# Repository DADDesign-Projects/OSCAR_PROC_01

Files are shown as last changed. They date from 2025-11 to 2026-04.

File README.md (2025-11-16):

# OSCAR Processor Board - OSCAR_PROC_01






# 📋 Description
Dedicated electronic board implementing the processor section of the OSCAR effects pedal (https://github.com/DADDesign-Projects/OSCAR_P01A01). This board handles digital signal processing and audio control for the OSCAR effects platform.

# 🛠️ Technical Specifications
## Microcontroller STM32H743:
 - High-performance ARM Cortex-M7 MCU
 -  480 MHz frequency
 -  2MB Flash memory
 -  1MB RAM
## Flash Memory 2* W25Q128
 - 32 Moctet.
 - Double mode 8 bits SPI;
 - 120 Mhz
## SDRAM Memory IS42S16320
 - 64 Moctet
 - 200 Mhz
## USB OTG FS
  - CDC Virtual port COM
  - UDP DownLoad Firmware Update
  - MIDI / USB
## I/O
  - 4 Encoders
  - 2 Switchs
## TFT
  - SPI inteface 
  - 2.4 inch 
## MIDI
  - UART TRS Midi in
## Orogramming/Debugging
  - STLink serial port
  - USB UDP protocol.

## 💻 Software
The circuit design software for this board is available in the OSCAR repository (https://github.com/DADDesign-Projects/OSCAR_P01A01). This project is built upon the DAD Forge framework (https://github.com/DADDesign-Projects/DAD_FORGE), which provides a standardized foundation for hardware development and collaboration.

## 🛠️ Design Tools
This project was entirely designed using KiCad 9.0, the open-source electronics design automation suite.
    
# 📬 Contact
Feel free to contact me for any questions, feedback, improvement suggestions, or collaboration proposals related to the FORGE framework or the OSCAR hardware platform.
I am always open to discussion and community contributions (daddesign.projects@gmail.com).  
  
---

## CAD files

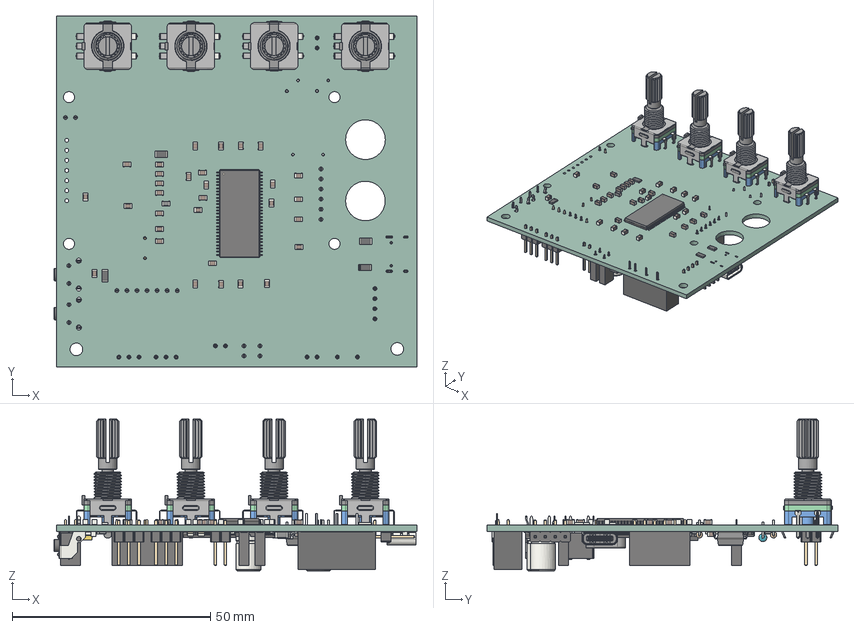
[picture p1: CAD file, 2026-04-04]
OSCAR_Proc.step
91.6 x 88.6 x 38.3 mm
C_0805_2012Metric x 36
EC11_Rotary_Encoder_Switched x 4
R_1206_3216Metric x 10
TSOP-II-54_22.2x10.16mm_P0.8mm
L_0805_2012Metric
LED_1206_3216Metric x 2
CP_Elec_6.3x9.9 x 2
SOIC-8_5.3x5.3mm_P1.27mm x 2
CP_EIA-3528-21_Kemet-B
PinSocket_1x07_P2.54mm_Vertical
PinSocket_1x02_P2.54mm_Vertical x 3
L_1206_3216Metric x 2
PinHeader_1x04_P2.54mm_Horizontal
SOT-23
USB_C_Receptacle_GCT_USB4105-xx-A_16P_TopMnt_Horizontal
SW_Tactile_SPST_Angled_PTS645Vx39-2LFS x 2
PinHeader_1x02_P2.54mm_Vertical x 2
Crystal_HC49-4H_Vertical
PinHeader_1x03_P2.54mm_Vertical x 2
B0512S-2W
D_DO-35_SOD27_P7.62mm_Horizontal
SOT-143
LQFP-176_24x24mm_P0.5mm
PinSocket_1x06_P2.54mm_Vertical
R_Axial_DIN0204_L3.6mm_D1.6mm_P7.62mm_Horizontal x 2
SOT-223
User Library-DIP-6-SMD
OSCAR_Proc_PCB

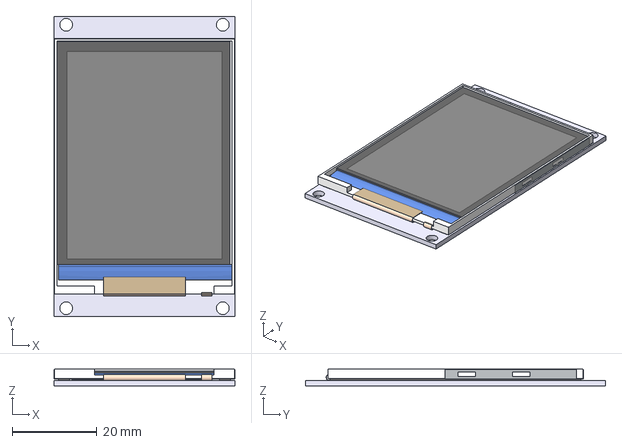
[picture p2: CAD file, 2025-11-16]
TFT_2_4_CStd.step
42.8 x 71.0 x 4.02 mm
2.4in TFT(Without Glass)- Tucked Cable
Corps

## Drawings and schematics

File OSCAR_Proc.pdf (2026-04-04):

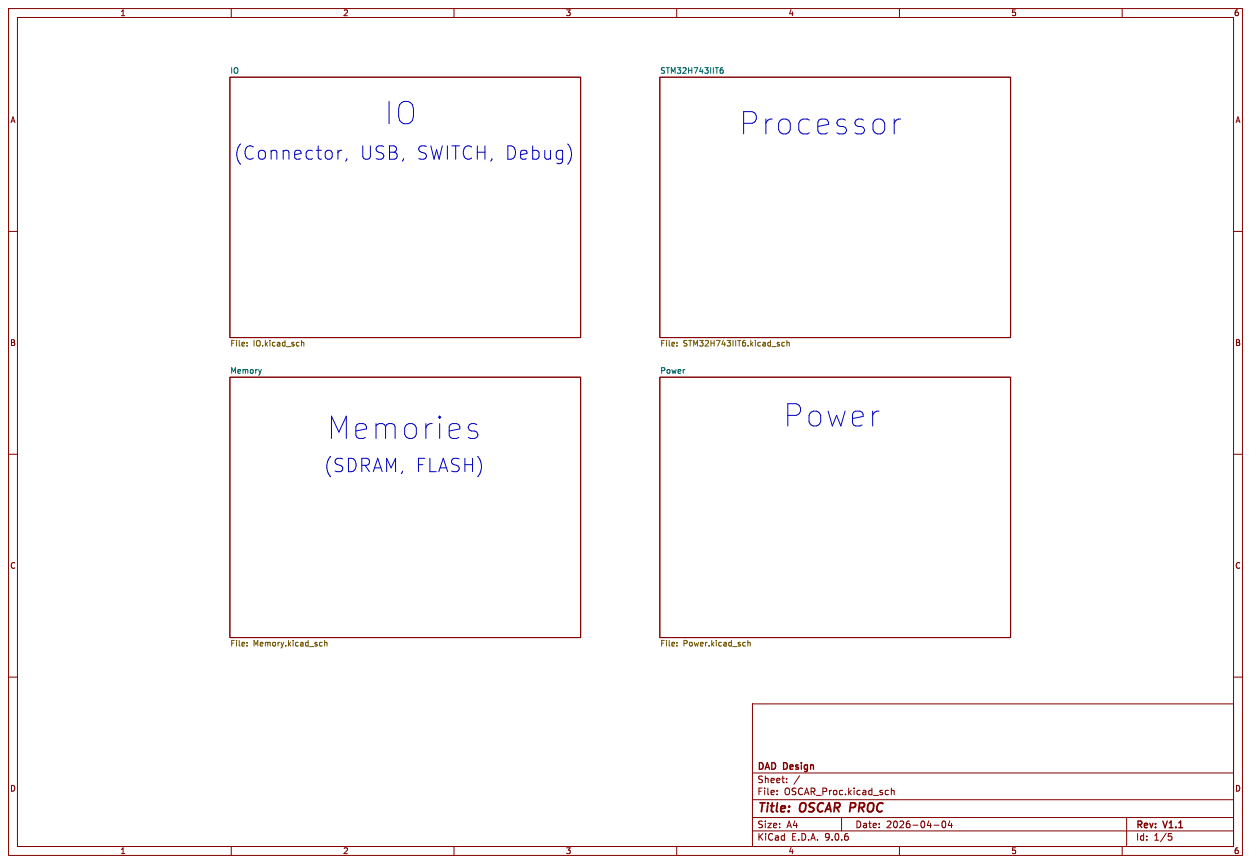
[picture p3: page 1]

File: IO.kicad_sch Memory File: Memory.kicad_sch

Id: 1/5 Title: OSCAR PROC

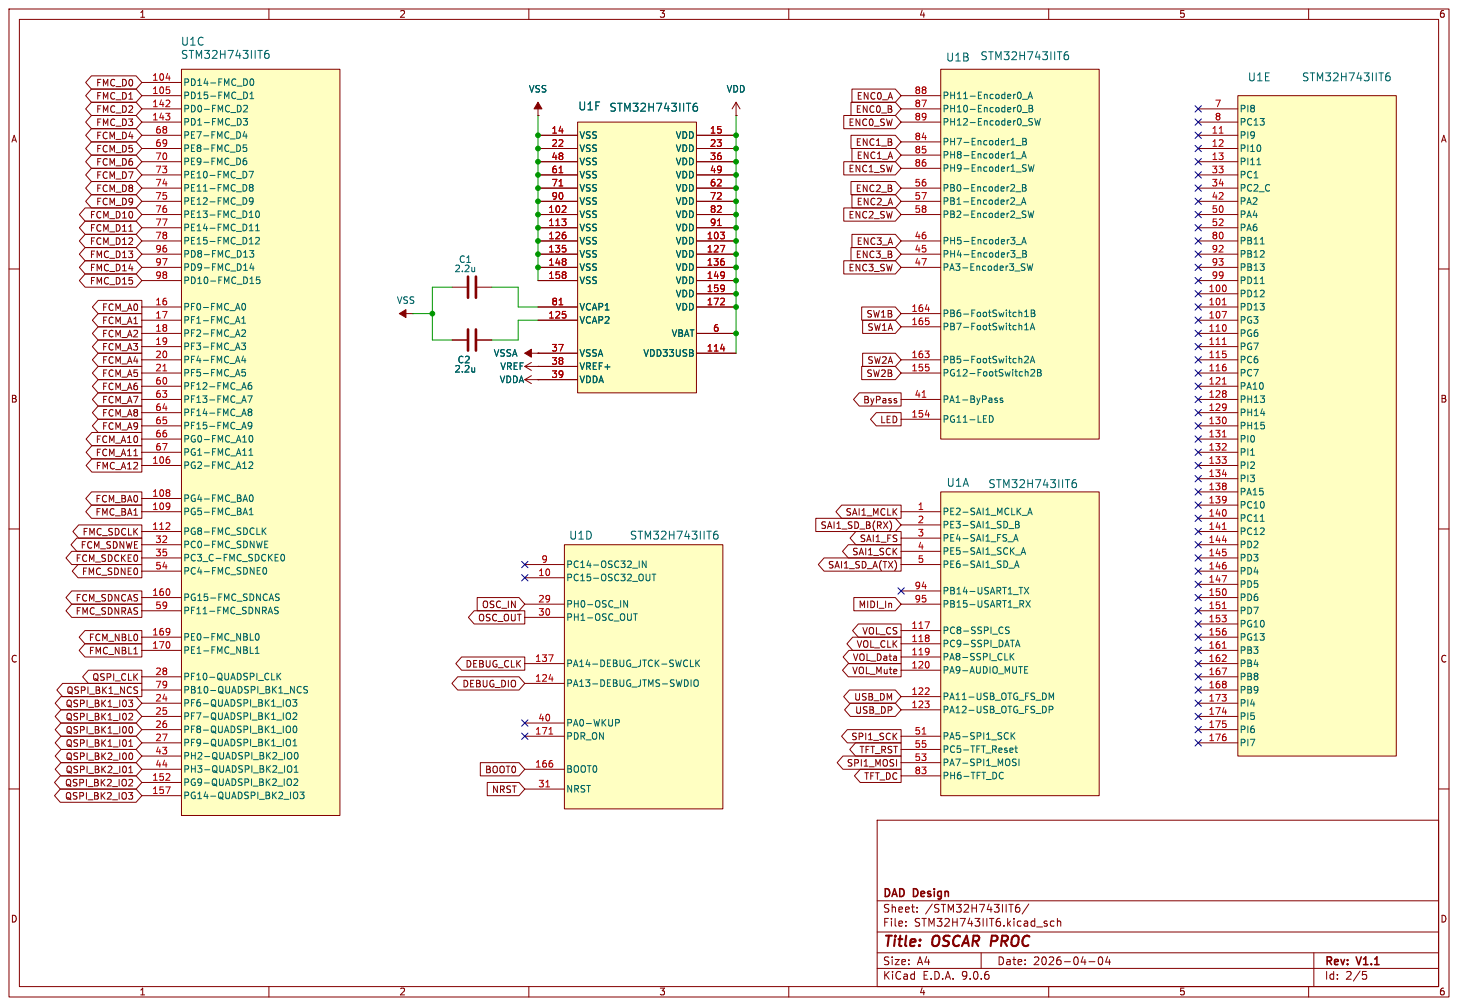
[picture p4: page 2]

Id: 2/5 Title: OSCAR PROC

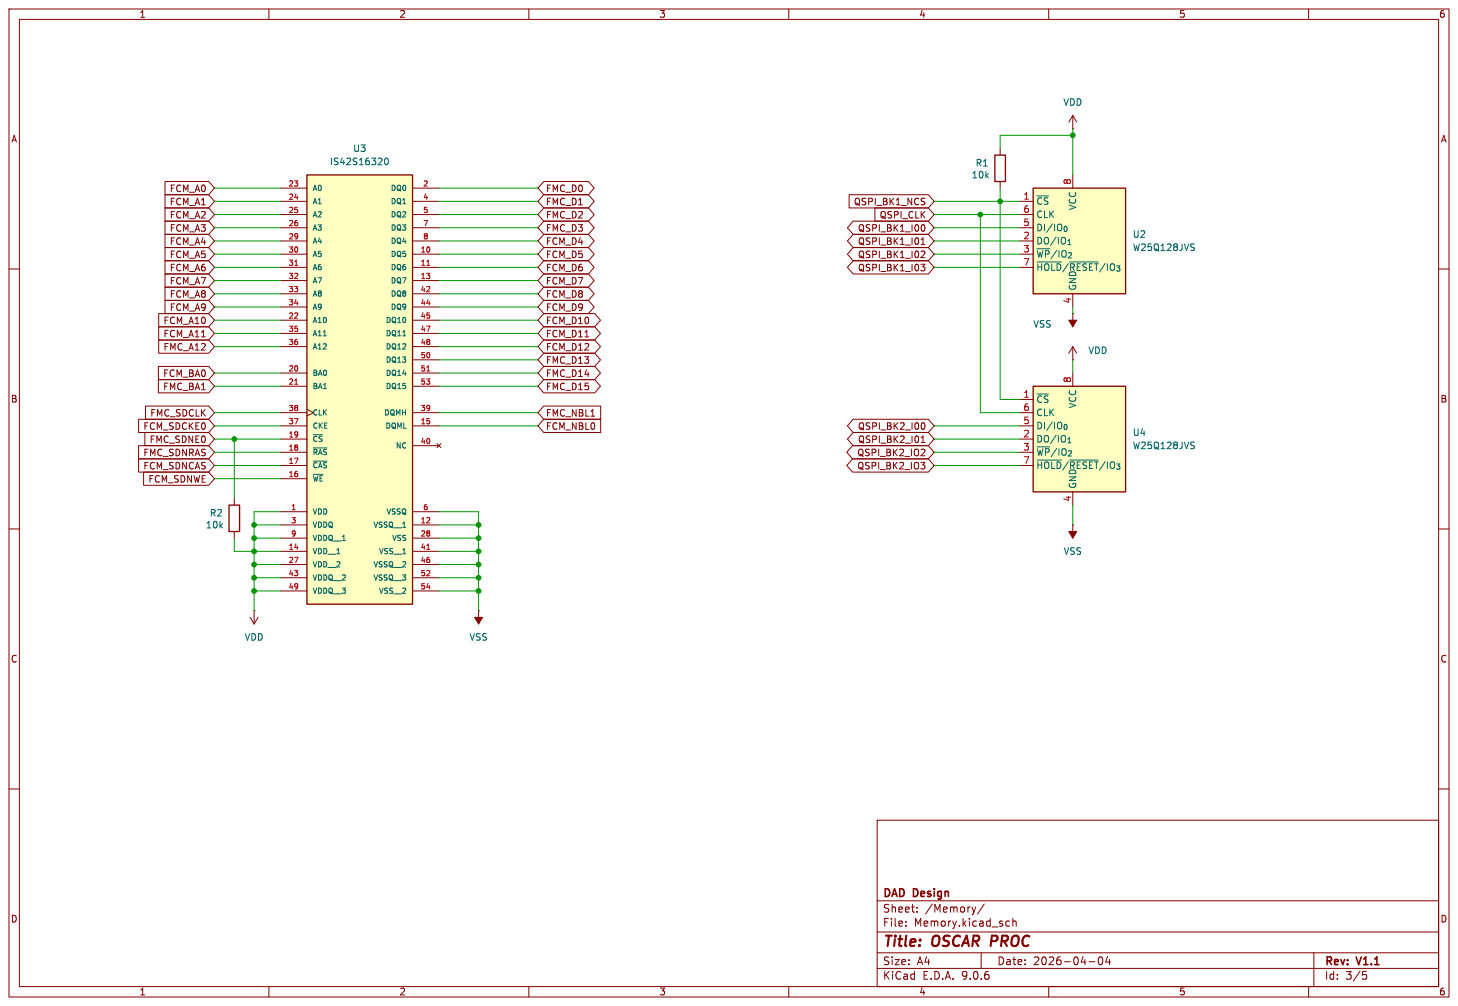
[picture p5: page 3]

Id: 3/5 Title: OSCAR PROC

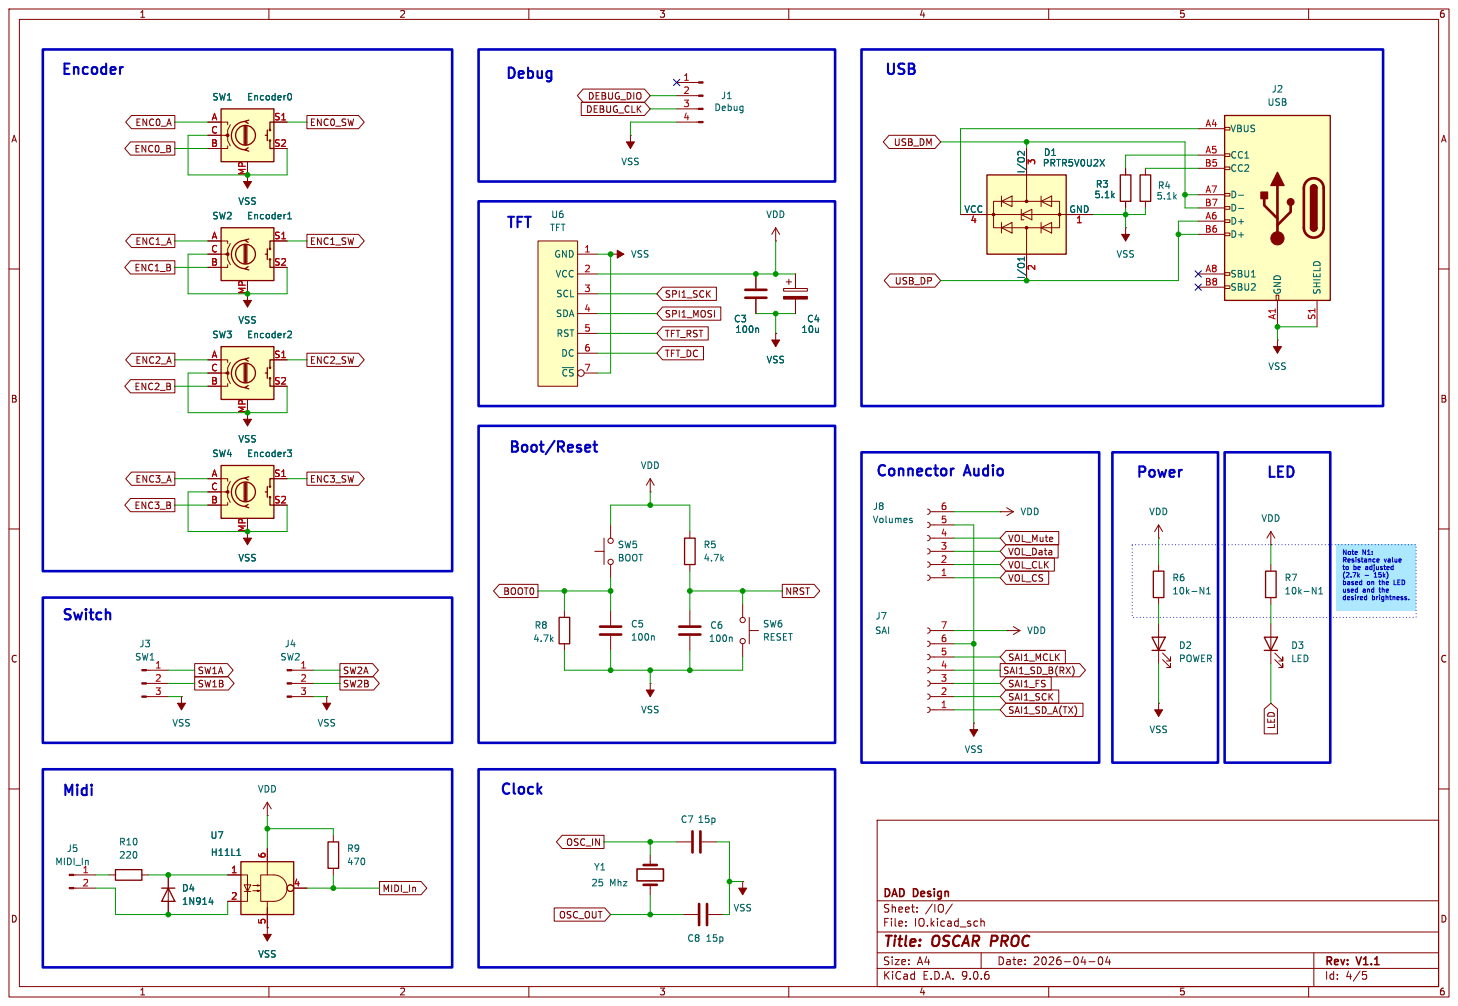
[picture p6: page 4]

to be adjusted
(2.7k - 15k) based on the LED

Id: 4/5 Title: OSCAR PROC

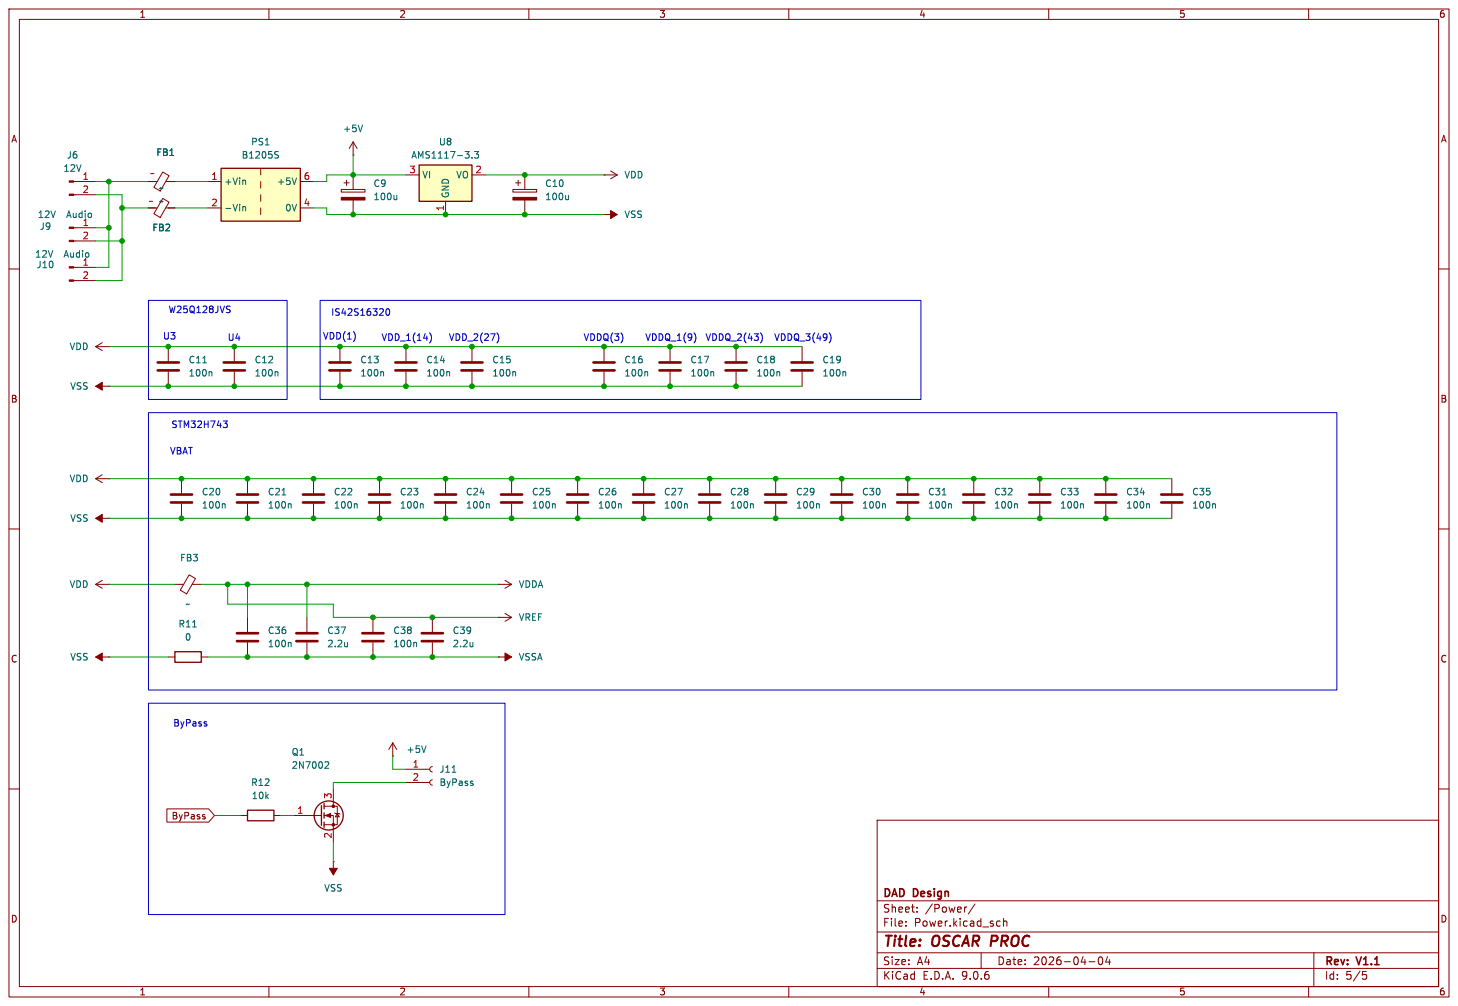
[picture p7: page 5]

Id: 5/5 Title: OSCAR PROC

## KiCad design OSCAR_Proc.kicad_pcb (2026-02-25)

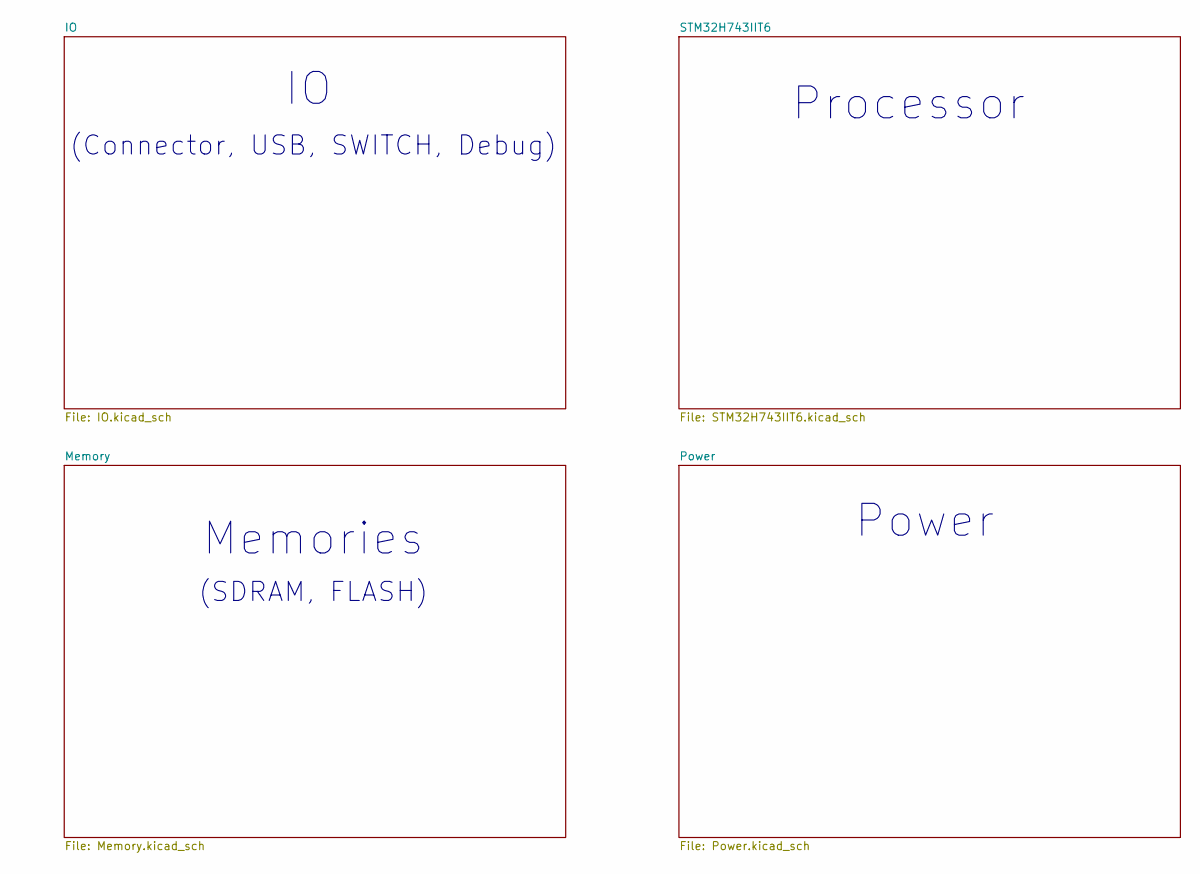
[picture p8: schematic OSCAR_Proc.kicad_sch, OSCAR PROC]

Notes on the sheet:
Processor
(Connector, USB, SWITCH, Debug)
Power
(SDRAM, FLASH)
Memories

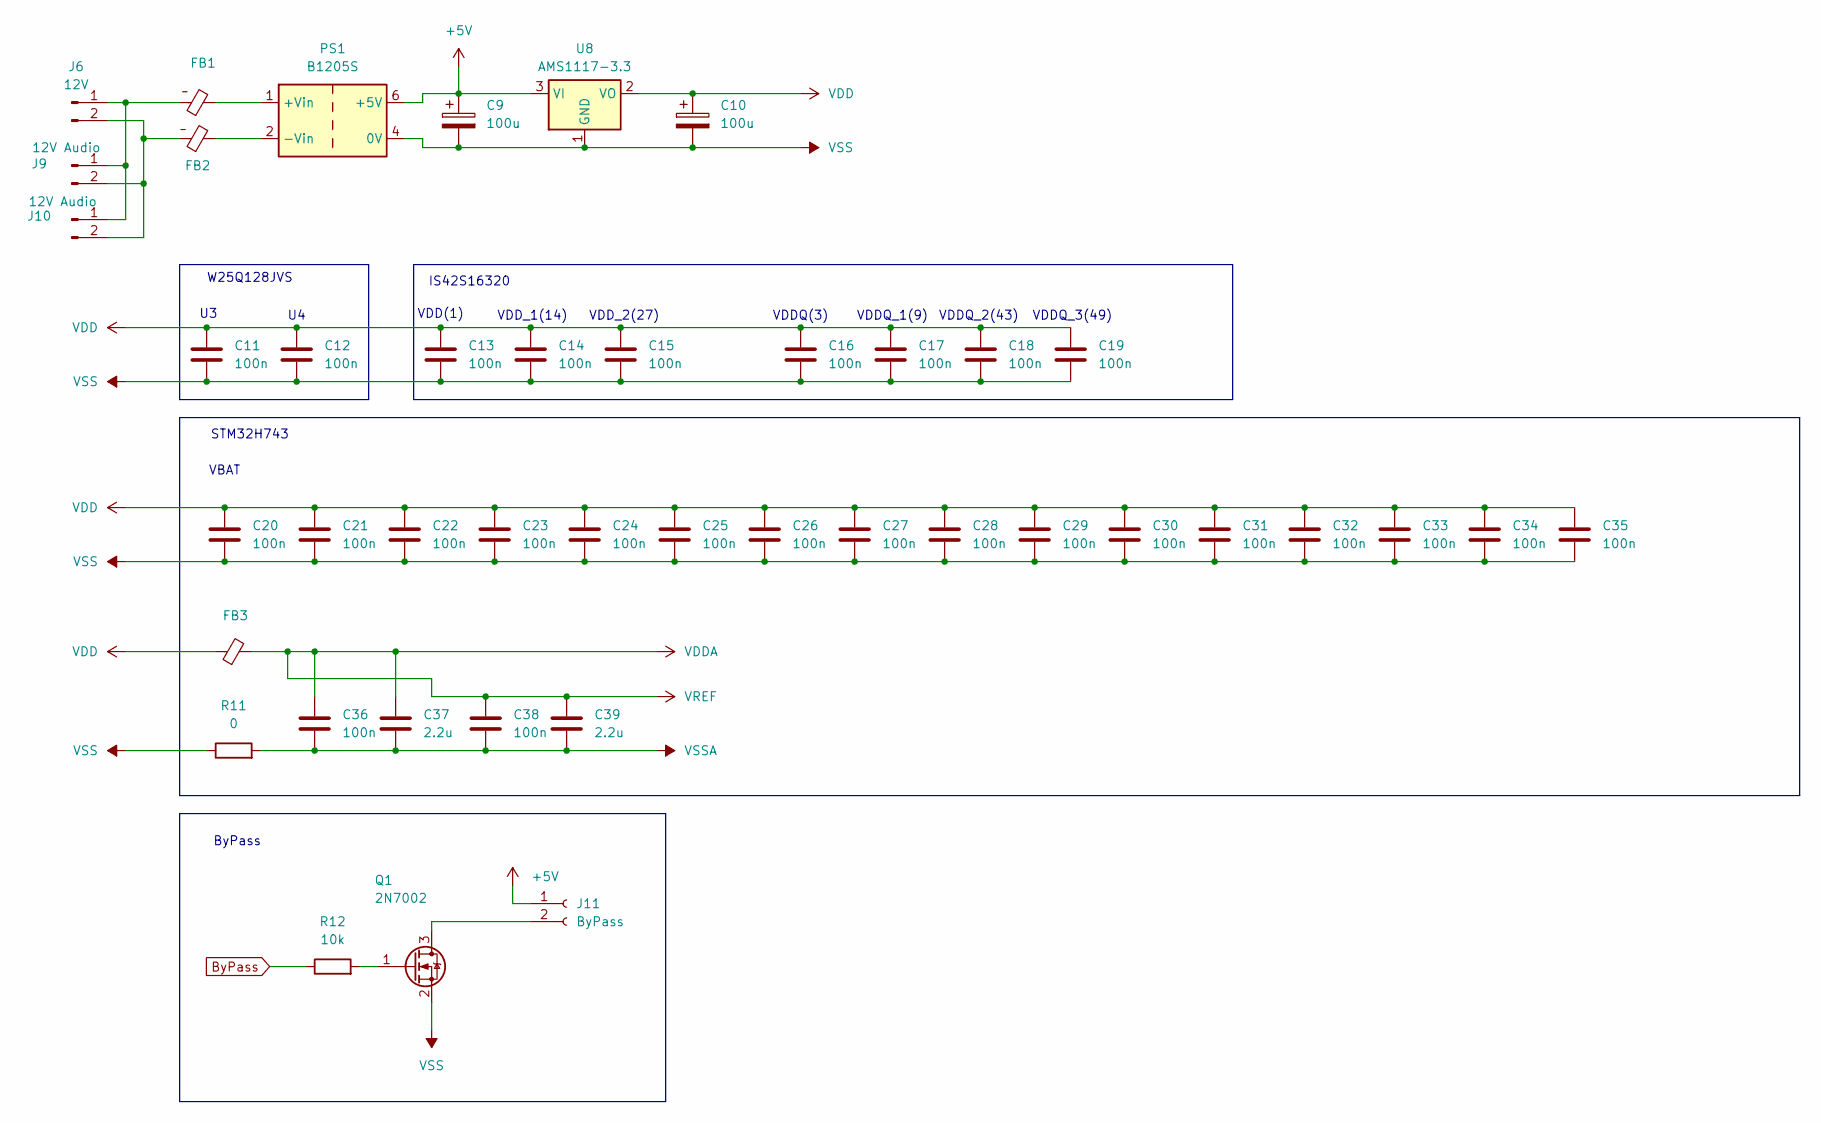
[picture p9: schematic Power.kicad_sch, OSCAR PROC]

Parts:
C9, C10: 100u; CP_Elec_6.3x9.9_WM
C11, C12, C13, C14, C15, C16, C17, C18, C19, C20, C21, C22, C23, C24, C25, C26, C27, C28, C29, C30, C31, C32, C33, C34, C35, C36, C38: 100n; C_0805_2012Metric_Pad1.18x1.45mm_HandSolder
C37, C39: 2.2u; C_0805_2012Metric_Pad1.18x1.45mm_HandSolder
FB1, FB2: L_1206_3216Metric_Pad1.22x1.90mm_HandSolder
FB3: L_0805_2012Metric_Pad1.15x1.40mm_HandSolder
J6: 12V; PinHeader_1x02_P2.54mm_Vertical
J9, J10: 12V Audio; PinSocket_1x02_P2.54mm_Vertical
J11: ByPass; PinSocket_1x02_P2.54mm_Vertical
PS1: B1205S; Converter_DCDC_TRACO_TBA1-xxxxE_Single_THT
Q1: 2N7002; SOT-23
R11: 0; R_1206_3216Metric_Pad1.30x1.75mm_HandSolder
R12: 10k; R_1206_3216Metric_Pad1.30x1.75mm_HandSolder
U8: AMS1117-3.3; SOT-223-3_TabPin2

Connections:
+5V: C9.1, J11.1, PS1.6 (+5V), U8.3 (VI)
ByPass: R12.1; also elsewhere on the board
unnamed: FB1.1, J6.1, J9.1, J10.1
unnamed: FB2.1, J6.2, J9.2, J10.2
unnamed: J11.2, Q1.3 (D)
unnamed: FB1.2, PS1.1 (+Vin)
unnamed: FB2.2, PS1.2 (-Vin)
unnamed: Q1.1 (G), R12.2
VDD: C10.1, C11.1, C12.1, C13.1, C14.1, C15.1, C16.1, C17.1, C18.1, C19.1, C20.1, C21.1, C22.1, C23.1, C24.1, C25.1, C26.1, C27.1, C28.1, C29.1, C30.1, C31.1, C32.1, C33.1, C34.1, C35.1, FB3.1, U8.2 (VO); also elsewhere on the board
VDDA: C36.1, C37.1, C38.1, C39.1, FB3.2; also elsewhere on the board
VSS: C9.2, C10.2, C11.2, C12.2, C13.2, C14.2, C15.2, C16.2, C17.2, C18.2, C19.2, C20.2, C21.2, C22.2, C23.2, C24.2, C25.2, C26.2, C27.2, C28.2, C29.2, C30.2, C31.2, C32.2, C33.2, C34.2, C35.2, PS1.4 (0V), Q1.2 (S), R11.1, U8.1 (GND); also elsewhere on the board
VSSA: C36.2, C37.2, C38.2, C39.2, R11.2; also elsewhere on the board

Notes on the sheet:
VDDQ_3(49)
ByPass
STM32H743
VDD(1)
VDD_1(14)
VDD_2(27)
VBAT
IS42S16320
VDDQ(3)
W25Q128JVS
VDDQ_1(9)
VDDQ_2(43)

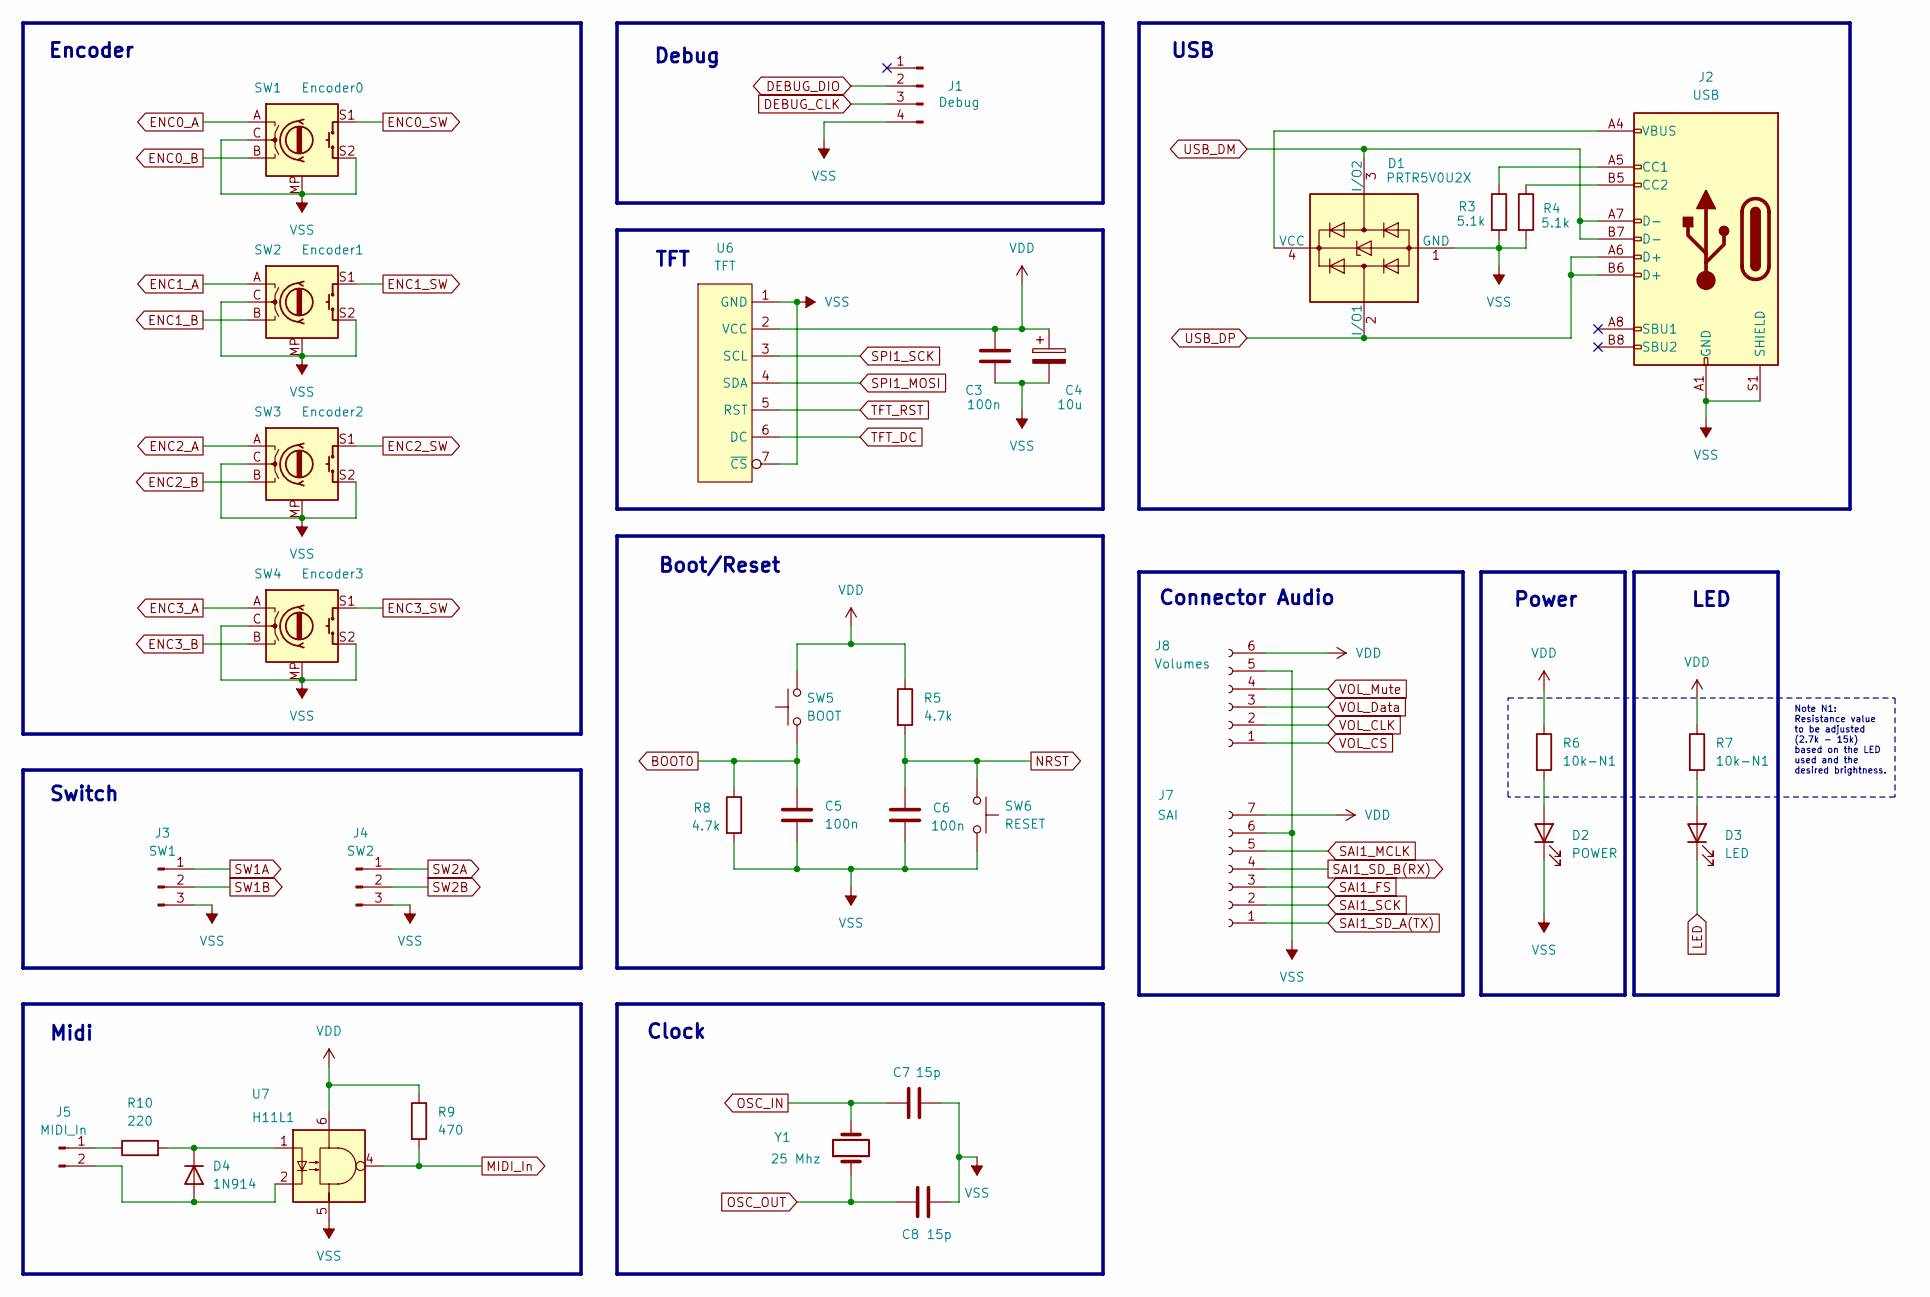
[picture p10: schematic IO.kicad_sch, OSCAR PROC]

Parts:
C3, C5, C6: 100n; C_0805_2012Metric_Pad1.18x1.45mm_HandSolder
C4: 10u; CP_EIA-3528-21_Kemet-B_HandSolder
C7, C8: 15p; C_0805_2012Metric_Pad1.18x1.45mm_HandSolder
D1: PRTR5V0U2X; SOT-143
D2: POWER; LED_1206_3216Metric_Pad1.42x1.75mm_HandSolder
D3: LED; LED_1206_3216Metric_Pad1.42x1.75mm_HandSolder
D4: 1N914; D_DO-35_SOD27_P7.62mm_Horizontal
J1: Debug; PinHeader_1x04_P2.54mm_Horizontal
J2: USB; USB_C_Receptacle_HCTL_HC-TYPE-C-16P-01A
J3: SW1; PinSocket_1x03_P2.54mm_Vertical
J4: SW2; PinSocket_1x03_P2.54mm_Vertical
J5: MIDI_In; PinHeader_1x02_P2.54mm_Vertical
J7: SAI; PinSocket_1x07_P2.54mm_Vertical
J8: Volumes; PinSocket_1x06_P2.54mm_Vertical
R3, R4: 5.1k; R_1206_3216Metric_Pad1.30x1.75mm_HandSolder
R5, R8: 4.7k; R_1206_3216Metric_Pad1.30x1.75mm_HandSolder
R6, R7: 10k-N1; R_1206_3216Metric_Pad1.30x1.75mm_HandSolder
R9: 470; R_Axial_DIN0204_L3.6mm_D1.6mm_P7.62mm_Horizontal
R10: 220; R_Axial_DIN0204_L3.6mm_D1.6mm_P7.62mm_Horizontal
SW1: Encoder0; RotaryEncoder
SW2: Encoder1; RotaryEncoder
SW3: Encoder2; RotaryEncoder
SW4: Encoder3; RotaryEncoder
SW5: BOOT; SW_Tactile_SPST_Angled_PTS645Vx39-2LFS
SW6: RESET; SW_Tactile_SPST_Angled_PTS645Vx39-2LFS
U6: TFT; TFT 2.4
U7: H11L1
Y1: 25 Mhz; Quartz

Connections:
BOOT0: C5.1, R8.1, SW5.1; also elsewhere on the board
DEBUG_CLK: J1.3; also elsewhere on the board
DEBUG_DIO: J1.2; also elsewhere on the board
ENC0_A: SW1.A; also elsewhere on the board
ENC0_B: SW1.B; also elsewhere on the board
ENC0_SW: SW1.S1; also elsewhere on the board
ENC1_A: SW2.A; also elsewhere on the board
ENC1_B: SW2.B; also elsewhere on the board
ENC1_SW: SW2.S1; also elsewhere on the board
ENC2_A: SW3.A; also elsewhere on the board
ENC2_B: SW3.B; also elsewhere on the board
ENC2_SW: SW3.S1; also elsewhere on the board
ENC3_A: SW4.A; also elsewhere on the board
ENC3_B: SW4.B; also elsewhere on the board
ENC3_SW: SW4.S1; also elsewhere on the board
LED: D3.1 (K); also elsewhere on the board
MIDI_In: R9.2, U7.4; also elsewhere on the board
NRST: C6.1, R5.2, SW6.1; also elsewhere on the board
unnamed: D1.4 (VCC), J2.A4 (VBUS), J2.A9 (VBUS), J2.B4 (VBUS), J2.B9 (VBUS)
unnamed: D2.2 (A), R6.2
unnamed: D3.2 (A), R7.2
unnamed: D4.2 (A), J5.2, U7.2
unnamed: D4.1 (K), R10.2, U7.1
unnamed: J2.A5 (CC1), R3.1
unnamed: J2.B5 (CC2), R4.1
unnamed: J5.1, R10.1
OSC_IN: C7.1, Y1.2; also elsewhere on the board
OSC_OUT: C8.1, Y1.1; also elsewhere on the board
SAI1_FS: J7.3; also elsewhere on the board
SAI1_MCLK: J7.5; also elsewhere on the board
SAI1_SCK: J7.2; also elsewhere on the board
SAI1_SD_A(TX): J7.1; also elsewhere on the board
SAI1_SD_B(RX): J7.4; also elsewhere on the board
SPI1_MOSI: U6.4 (SDA); also elsewhere on the board
SPI1_SCK: U6.3 (SCL); also elsewhere on the board
SW1A: J3.1; also elsewhere on the board
SW1B: J3.2; also elsewhere on the board
SW2A: J4.1; also elsewhere on the board
SW2B: J4.2; also elsewhere on the board
TFT_DC: U6.6 (DC); also elsewhere on the board
TFT_RST: U6.5 (RST); also elsewhere on the board
USB_DM: D1.3 (I/O2), J2.A7 (D-), J2.B7 (D-); also elsewhere on the board
USB_DP: D1.2 (I/O1), J2.A6 (D+), J2.B6 (D+); also elsewhere on the board
VDD: C3.1, C4.1, J7.7, J8.6, R5.1, R6.1, R7.1, R9.1, SW5.2, U6.2 (VCC), U7.6; also elsewhere on the board
VOL_CLK: J8.2; also elsewhere on the board
VOL_CS: J8.1; also elsewhere on the board
VOL_Data: J8.3; also elsewhere on the board
VOL_Mute: J8.4; also elsewhere on the board
VSS: C3.2, C4.2, C5.2, C6.2, C7.2, C8.2, D1.1 (GND), D2.1 (K), J1.4, J2.A1 (GND), J2.A12 (GND), J2.B1 (GND), J2.B12 (GND), J2.S1 (SHIELD), J3.3, J4.3, J7.6, J8.5, R3.2, R4.2, R8.2, SW1.C, SW1.MP, SW1.S2, SW2.C, SW2.MP, SW2.S2, SW3.C, SW3.MP, SW3.S2, SW4.C, SW4.MP, SW4.S2, SW6.2, U6.1 (GND), U6.7 (~CS), U7.5; also elsewhere on the board

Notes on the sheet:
USB
Clock
TFT
Boot/Reset
Debug
Encoder
Switch
LED
Midi
Power
Connector Audio
Note N1: Resistance value to be adjusted (2.7k - 15k) based on the LED used and the desired brightness.

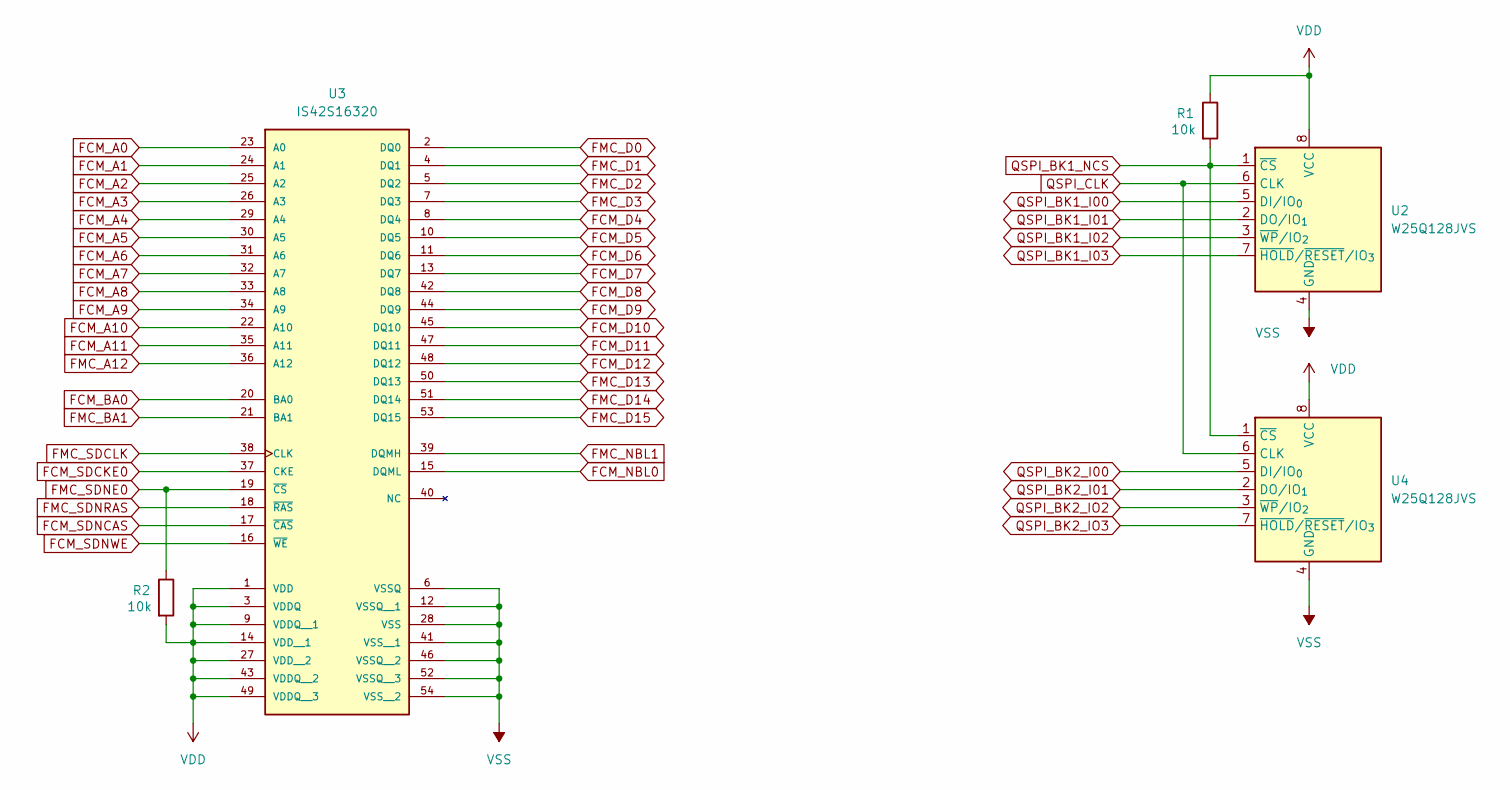
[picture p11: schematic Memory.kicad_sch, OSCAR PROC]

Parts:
R1, R2: 10k; R_1206_3216Metric_Pad1.30x1.75mm_HandSolder
U2, U4: W25Q128JVS; SOIC-8_5.3x5.3mm_P1.27mm
U3: IS42S16320; TSOP-II-54_22.2x10.16mm_P0.8mm; PARTREV B1

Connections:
FCM_A0: U3.23 (A0); also elsewhere on the board
FCM_A1: U3.24 (A1); also elsewhere on the board
FCM_A2: U3.25 (A2); also elsewhere on the board
FCM_A3: U3.26 (A3); also elsewhere on the board
FCM_A4: U3.29 (A4); also elsewhere on the board
FCM_A5: U3.30 (A5); also elsewhere on the board
FCM_A6: U3.31 (A6); also elsewhere on the board
FCM_A7: U3.32 (A7); also elsewhere on the board
FCM_A8: U3.33 (A8); also elsewhere on the board
FCM_A9: U3.34 (A9); also elsewhere on the board
FCM_A10: U3.22 (A10); also elsewhere on the board
FCM_A11: U3.35 (A11); also elsewhere on the board
FCM_BA0: U3.20 (BA0); also elsewhere on the board
FCM_D4: U3.8 (DQ4); also elsewhere on the board
FCM_D5: U3.10 (DQ5); also elsewhere on the board
FCM_D6: U3.11 (DQ6); also elsewhere on the board
FCM_D7: U3.13 (DQ7); also elsewhere on the board
FCM_D8: U3.42 (DQ8); also elsewhere on the board
FCM_D9: U3.44 (DQ9); also elsewhere on the board
FCM_D10: U3.45 (DQ10); also elsewhere on the board
FCM_D11: U3.47 (DQ11); also elsewhere on the board
FCM_D12: U3.48 (DQ12); also elsewhere on the board
FCM_NBL0: U3.15 (DQML); also elsewhere on the board
FCM_SDCKE0: U3.37 (CKE); also elsewhere on the board
FCM_SDNCAS: U3.17 (~CAS); also elsewhere on the board
FCM_SDNWE: U3.16 (~WE); also elsewhere on the board
FMC_A12: U3.36 (A12); also elsewhere on the board
FMC_BA1: U3.21 (BA1); also elsewhere on the board
FMC_D0: U3.2 (DQ0); also elsewhere on the board
FMC_D1: U3.4 (DQ1); also elsewhere on the board
FMC_D2: U3.5 (DQ2); also elsewhere on the board
FMC_D3: U3.7 (DQ3); also elsewhere on the board
FMC_D13: U3.50 (DQ13); also elsewhere on the board
FMC_D14: U3.51 (DQ14); also elsewhere on the board
FMC_D15: U3.53 (DQ15); also elsewhere on the board
FMC_NBL1: U3.39 (DQMH); also elsewhere on the board
FMC_SDCLK: U3.38 (CLK); also elsewhere on the board
FMC_SDNE0: R2.1, U3.19 (~CS); also elsewhere on the board
FMC_SDNRAS: U3.18 (~RAS); also elsewhere on the board
QSPI_BK1_NCS: R1.2, U2.1 (~CS), U4.1 (~CS); also elsewhere on the board
QSPI_BK2_I00: U4.5 (DI/IO_{0}); also elsewhere on the board
QSPI_BK2_I01: U4.2 (DO/IO_{1}); also elsewhere on the board
QSPI_BK2_IO2: U4.3 (~WP/IO_{2}); also elsewhere on the board
QSPI_BK2_IO3: U4.7 (~HOLD/~RESET/IO_{3}); also elsewhere on the board
QSPI_CLK: U2.6 (CLK), U4.6 (CLK); also elsewhere on the board
VDD: R1.1, R2.2, U2.8 (VCC), U3.1 (VDD), U3.3 (VDDQ), U3.9 (VDDQ__1), U3.14 (VDD__1), U3.27 (VDD__2), U3.43 (VDDQ__2), U3.49 (VDDQ__3), U4.8 (VCC); also elsewhere on the board
VSS: U2.4 (GND), U3.6 (VSSQ), U3.12 (VSSQ__1), U3.28 (VSS), U3.41 (VSS__1), U3.46 (VSSQ__2), U3.52 (VSSQ__3), U3.54 (VSS__2), U4.4 (GND); also elsewhere on the board

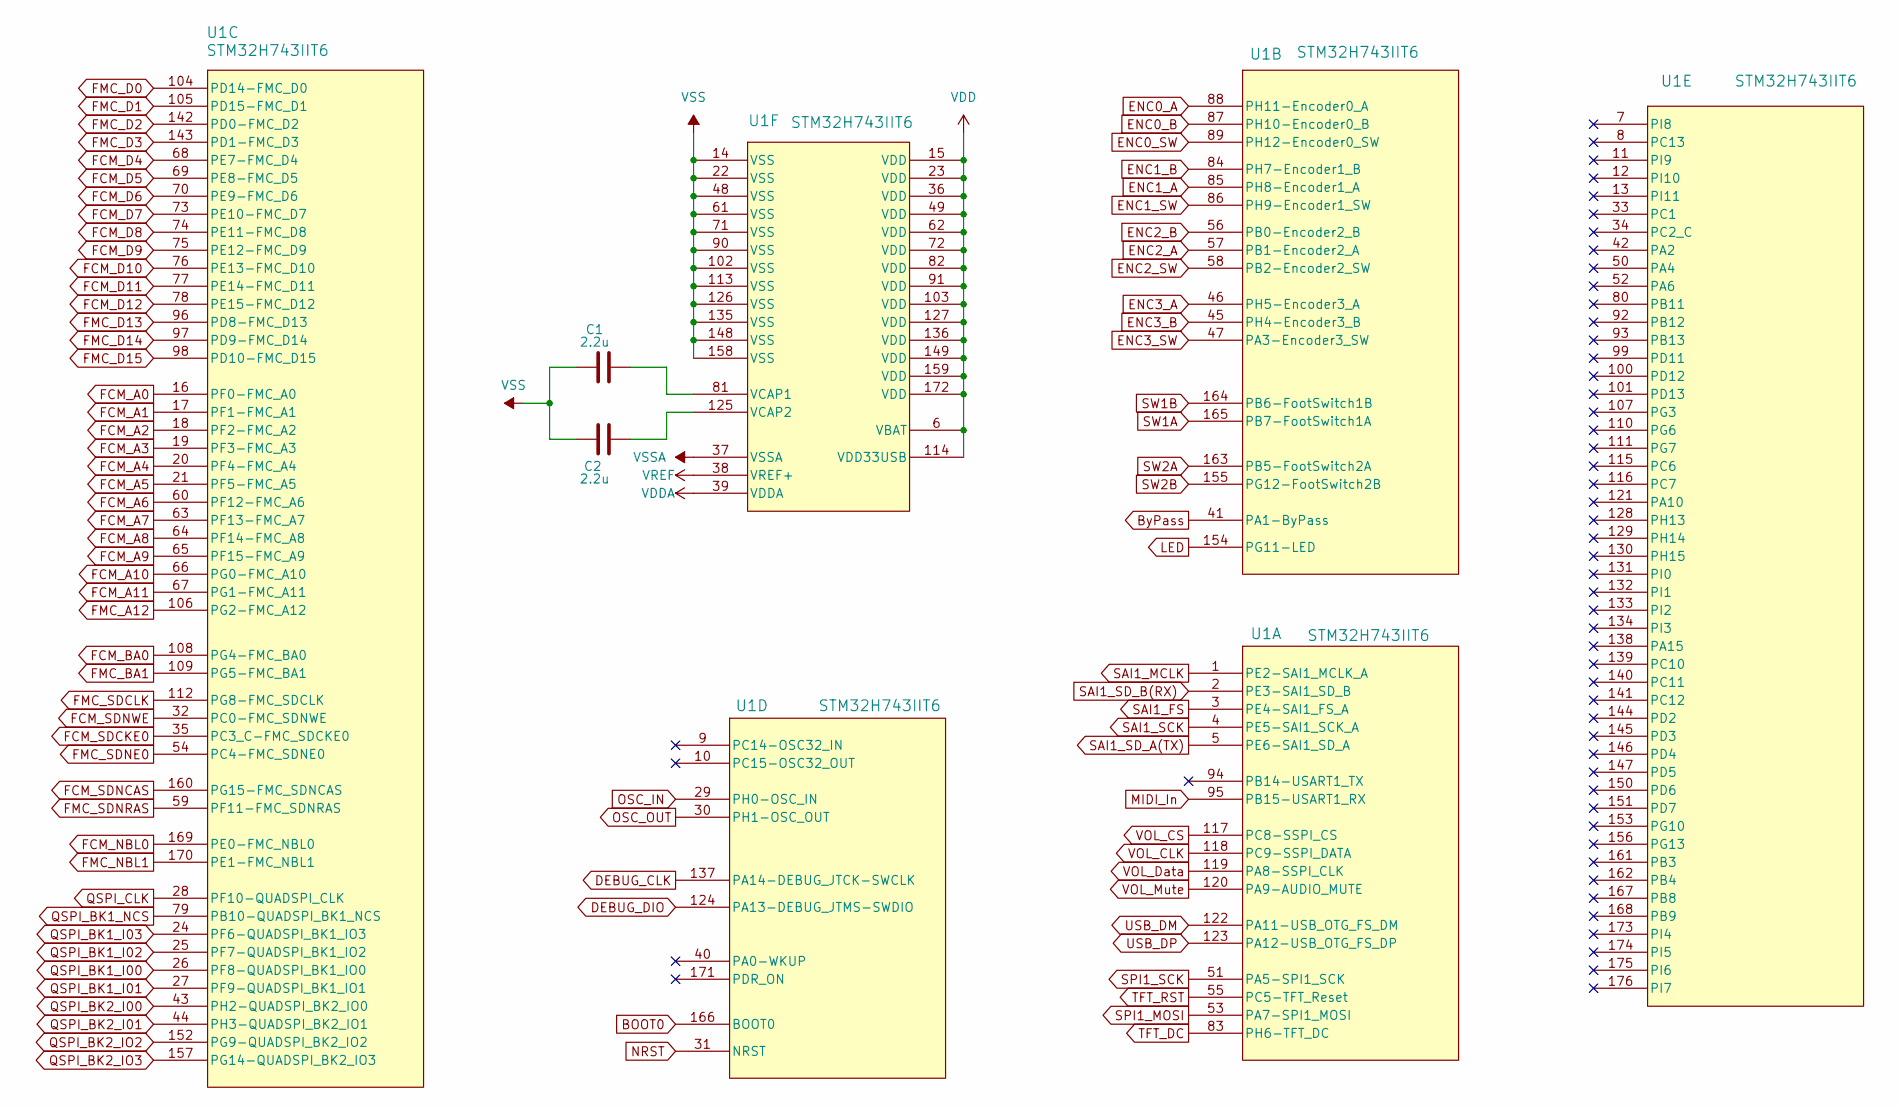
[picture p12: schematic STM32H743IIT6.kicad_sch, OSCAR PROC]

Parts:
C1, C2: 2.2u; C_0805_2012Metric_Pad1.18x1.45mm_HandSolder
U1: STM32H743IIT6; LQFP176-24x24mm-M

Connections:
BOOT0: U1.166 (BOOT0); also elsewhere on the board
ByPass: U1.41 (PA1-ByPass); also elsewhere on the board
DEBUG_CLK: U1.137 (PA14-DEBUG_JTCK-SWCLK); also elsewhere on the board
DEBUG_DIO: U1.124 (PA13-DEBUG_JTMS-SWDIO); also elsewhere on the board
ENC0_A: U1.88 (PH11-Encoder0_A); also elsewhere on the board
ENC0_B: U1.87 (PH10-Encoder0_B); also elsewhere on the board
ENC0_SW: U1.89 (PH12-Encoder0_SW); also elsewhere on the board
ENC1_A: U1.85 (PH8-Encoder1_A); also elsewhere on the board
ENC1_B: U1.84 (PH7-Encoder1_B); also elsewhere on the board
ENC1_SW: U1.86 (PH9-Encoder1_SW); also elsewhere on the board
ENC2_A: U1.57 (PB1-Encoder2_A); also elsewhere on the board
ENC2_B: U1.56 (PB0-Encoder2_B); also elsewhere on the board
ENC2_SW: U1.58 (PB2-Encoder2_SW); also elsewhere on the board
ENC3_A: U1.46 (PH5-Encoder3_A); also elsewhere on the board
ENC3_B: U1.45 (PH4-Encoder3_B); also elsewhere on the board
ENC3_SW: U1.47 (PA3-Encoder3_SW); also elsewhere on the board
FCM_A0: U1.16 (PF0-FMC_A0); also elsewhere on the board
FCM_A1: U1.17 (PF1-FMC_A1); also elsewhere on the board
FCM_A2: U1.18 (PF2-FMC_A2); also elsewhere on the board
FCM_A3: U1.19 (PF3-FMC_A3); also elsewhere on the board
FCM_A4: U1.20 (PF4-FMC_A4); also elsewhere on the board
FCM_A5: U1.21 (PF5-FMC_A5); also elsewhere on the board
FCM_A6: U1.60 (PF12-FMC_A6); also elsewhere on the board
FCM_A7: U1.63 (PF13-FMC_A7); also elsewhere on the board
FCM_A8: U1.64 (PF14-FMC_A8); also elsewhere on the board
FCM_A9: U1.65 (PF15-FMC_A9); also elsewhere on the board
FCM_A10: U1.66 (PG0-FMC_A10); also elsewhere on the board
FCM_A11: U1.67 (PG1-FMC_A11); also elsewhere on the board
FCM_BA0: U1.108 (PG4-FMC_BA0); also elsewhere on the board
FCM_D4: U1.68 (PE7-FMC_D4); also elsewhere on the board
FCM_D5: U1.69 (PE8-FMC_D5); also elsewhere on the board
FCM_D6: U1.70 (PE9-FMC_D6); also elsewhere on the board
FCM_D7: U1.73 (PE10-FMC_D7); also elsewhere on the board
FCM_D8: U1.74 (PE11-FMC_D8); also elsewhere on the board
FCM_D9: U1.75 (PE12-FMC_D9); also elsewhere on the board
FCM_D10: U1.76 (PE13-FMC_D10); also elsewhere on the board
FCM_D11: U1.77 (PE14-FMC_D11); also elsewhere on the board
FCM_D12: U1.78 (PE15-FMC_D12); also elsewhere on the board
FCM_NBL0: U1.169 (PE0-FMC_NBL0); also elsewhere on the board
FCM_SDCKE0: U1.35 (PC3_C-FMC_SDCKE0); also elsewhere on the board
FCM_SDNCAS: U1.160 (PG15-FMC_SDNCAS); also elsewhere on the board
FCM_SDNWE: U1.32 (PC0-FMC_SDNWE); also elsewhere on the board
FMC_A12: U1.106 (PG2-FMC_A12); also elsewhere on the board
FMC_BA1: U1.109 (PG5-FMC_BA1); also elsewhere on the board
FMC_D0: U1.104 (PD14-FMC_D0); also elsewhere on the board
FMC_D1: U1.105 (PD15-FMC_D1); also elsewhere on the board
FMC_D2: U1.142 (PD0-FMC_D2); also elsewhere on the board
FMC_D3: U1.143 (PD1-FMC_D3); also elsewhere on the board
FMC_D13: U1.96 (PD8-FMC_D13); also elsewhere on the board
FMC_D14: U1.97 (PD9-FMC_D14); also elsewhere on the board
FMC_D15: U1.98 (PD10-FMC_D15); also elsewhere on the board
FMC_NBL1: U1.170 (PE1-FMC_NBL1); also elsewhere on the board
FMC_SDCLK: U1.112 (PG8-FMC_SDCLK); also elsewhere on the board
FMC_SDNE0: U1.54 (PC4-FMC_SDNE0); also elsewhere on the board
FMC_SDNRAS: U1.59 (PF11-FMC_SDNRAS); also elsewhere on the board
LED: U1.154 (PG11-LED); also elsewhere on the board
MIDI_In: U1.95 (PB15-USART1_RX); also elsewhere on the board
NRST: U1.31 (NRST); also elsewhere on the board
unnamed: C1.2, U1.81 (VCAP1)
unnamed: C2.2, U1.125 (VCAP2)
OSC_IN: U1.29 (PH0-OSC_IN); also elsewhere on the board
OSC_OUT: U1.30 (PH1-OSC_OUT); also elsewhere on the board
QSPI_BK1_I00: U1.26 (PF8-QUADSPI_BK1_IO0); also elsewhere on the board
QSPI_BK1_I01: U1.27 (PF9-QUADSPI_BK1_IO1); also elsewhere on the board
QSPI_BK1_I02: U1.25 (PF7-QUADSPI_BK1_IO2); also elsewhere on the board
QSPI_BK1_I03: U1.24 (PF6-QUADSPI_BK1_IO3); also elsewhere on the board
QSPI_BK1_NCS: U1.79 (PB10-QUADSPI_BK1_NCS); also elsewhere on the board
QSPI_BK2_I00: U1.43 (PH2-QUADSPI_BK2_IO0); also elsewhere on the board
QSPI_BK2_I01: U1.44 (PH3-QUADSPI_BK2_IO1); also elsewhere on the board
QSPI_BK2_IO2: U1.152 (PG9-QUADSPI_BK2_IO2); also elsewhere on the board
QSPI_BK2_IO3: U1.157 (PG14-QUADSPI_BK2_IO3); also elsewhere on the board
QSPI_CLK: U1.28 (PF10-QUADSPI_CLK); also elsewhere on the board
SAI1_FS: U1.3 (PE4-SAI1_FS_A); also elsewhere on the board
SAI1_MCLK: U1.1 (PE2-SAI1_MCLK_A); also elsewhere on the board
SAI1_SCK: U1.4 (PE5-SAI1_SCK_A); also elsewhere on the board
SAI1_SD_A(TX): U1.5 (PE6-SAI1_SD_A); also elsewhere on the board
SAI1_SD_B(RX): U1.2 (PE3-SAI1_SD_B); also elsewhere on the board
SPI1_MOSI: U1.53 (PA7-SPI1_MOSI); also elsewhere on the board
SPI1_SCK: U1.51 (PA5-SPI1_SCK); also elsewhere on the board
SW1A: U1.165 (PB7-FootSwitch1A); also elsewhere on the board
SW1B: U1.164 (PB6-FootSwitch1B); also elsewhere on the board
SW2A: U1.163 (PB5-FootSwitch2A); also elsewhere on the board
SW2B: U1.155 (PG12-FootSwitch2B); also elsewhere on the board
TFT_DC: U1.83 (PH6-TFT_DC); also elsewhere on the board
TFT_RST: U1.55 (PC5-TFT_Reset); also elsewhere on the board
USB_DM: U1.122 (PA11-USB_OTG_FS_DM); also elsewhere on the board
USB_DP: U1.123 (PA12-USB_OTG_FS_DP); also elsewhere on the board
VDD: U1.6 (VBAT), U1.15 (VDD), U1.23 (VDD), U1.36 (VDD), U1.49 (VDD), U1.62 (VDD), U1.72 (VDD), U1.82 (VDD), U1.91 (VDD), U1.103 (VDD), U1.114 (VDD33USB), U1.127 (VDD), U1.136 (VDD), U1.149 (VDD), U1.159 (VDD), U1.172 (VDD); also elsewhere on the board
VDDA: U1.38 (VREF+), U1.39 (VDDA); also elsewhere on the board
VOL_CLK: U1.118 (PC9-SSPI_DATA); also elsewhere on the board
VOL_CS: U1.117 (PC8-SSPI_CS); also elsewhere on the board
VOL_Data: U1.119 (PA8-SSPI_CLK); also elsewhere on the board
VOL_Mute: U1.120 (PA9-AUDIO_MUTE); also elsewhere on the board
VSS: C1.1, C2.1, U1.14 (VSS), U1.22 (VSS), U1.48 (VSS), U1.61 (VSS), U1.71 (VSS), U1.90 (VSS), U1.102 (VSS), U1.113 (VSS), U1.126 (VSS), U1.135 (VSS), U1.148 (VSS), U1.158 (VSS); also elsewhere on the board
VSSA: U1.37 (VSSA); also elsewhere on the board

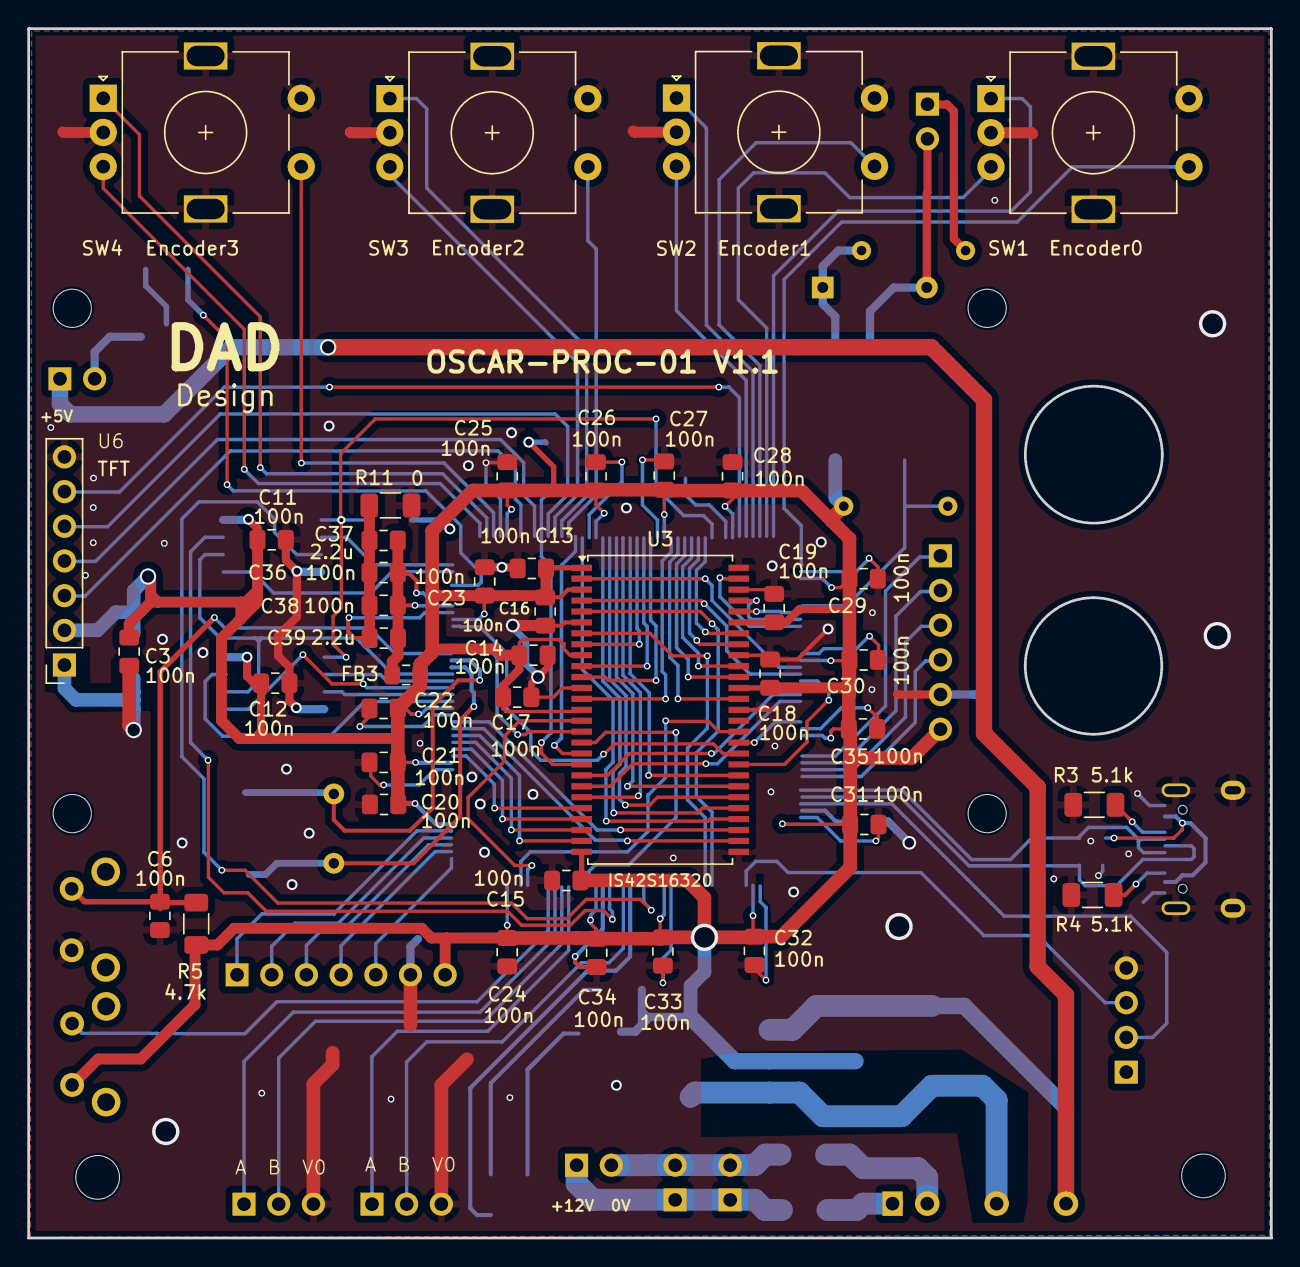
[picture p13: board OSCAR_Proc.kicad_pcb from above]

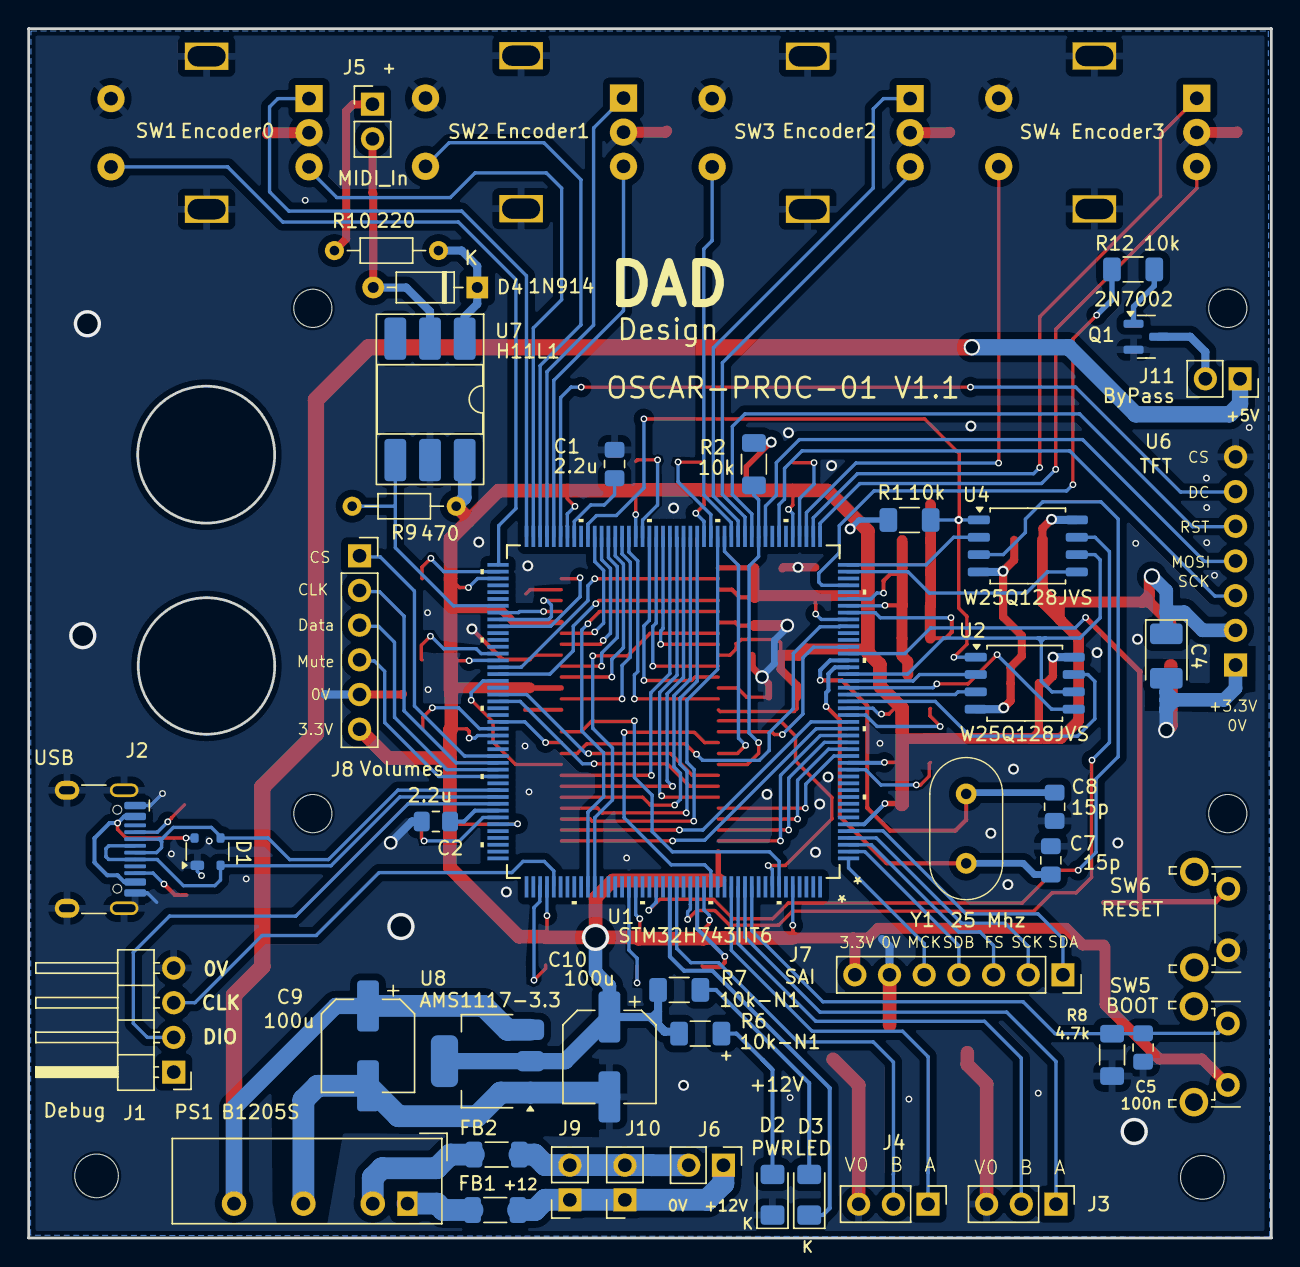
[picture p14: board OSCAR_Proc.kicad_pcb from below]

Board: 2 copper layers, 91.0 x 88.6 mm, 87 parts (43 on the bottom side), 110 nets.

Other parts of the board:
H1: MountingHole_3.2mm_M3
U2#2: W25Q128JVS; SOIC-8_5.3x5.3mm_P1.27mm

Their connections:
QSPI_BK1_I00: U2#2.5 (DI/IO_{0}); also elsewhere on the board
QSPI_BK1_I01: U2#2.2 (DO/IO_{1}); also elsewhere on the board
QSPI_BK1_I02: U2#2.3 (~WP/IO_{2}); also elsewhere on the board
QSPI_BK1_I03: U2#2.7 (~HOLD/~RESET/IO_{3}); also elsewhere on the board
QSPI_BK1_NCS: U2#2.1 (~CS); also elsewhere on the board
QSPI_CLK: U2#2.6 (CLK); also elsewhere on the board
VDD: U2#2.8 (VCC); also elsewhere on the board
VSS: U2#2.4 (GND); also elsewhere on the board

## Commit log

2026-02-25 Reposition footswitch connectors and LEDs
    - Moved footswitch connectors to support vertical placement
    - Adjusted LED positions for better visibility
    [OSCAR_Proc-B_Cu.gbr, OSCAR_Proc-B_Mask.gbr, OSCAR_Proc-B_Paste.gbr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]
2026-04-04 Reposition footswitch connectors and LEDs
    [IO.kicad_sch, Memory.kicad_sch, OSCAR_Proc.kicad_sch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]

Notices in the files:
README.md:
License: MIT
